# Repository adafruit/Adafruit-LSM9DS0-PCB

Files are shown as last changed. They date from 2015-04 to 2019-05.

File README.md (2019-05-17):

# Adafruit LSM9DS0 PCB (Discontinued)
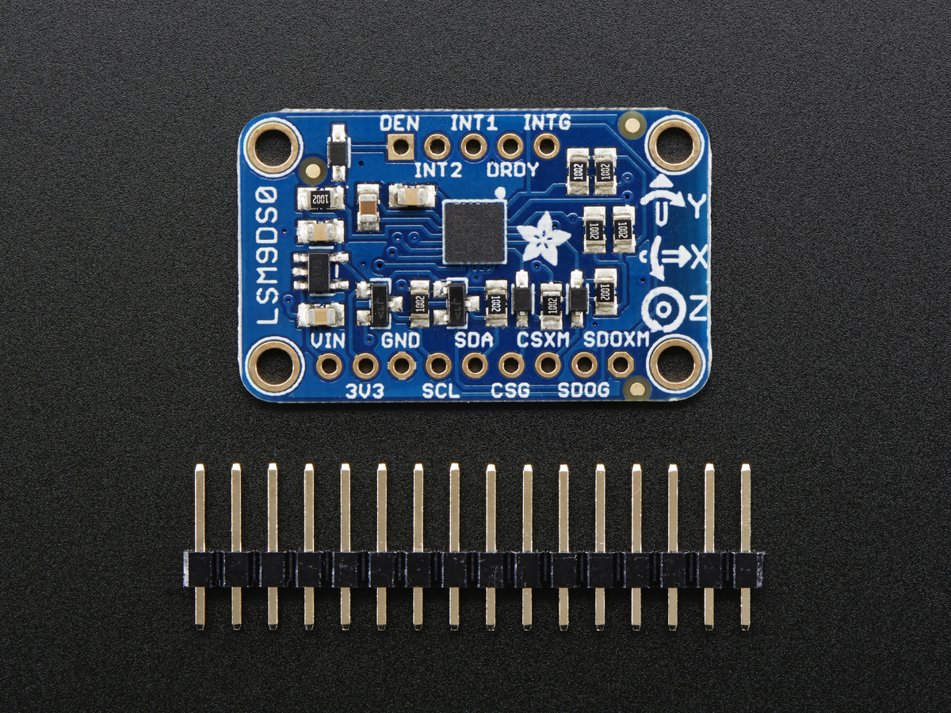
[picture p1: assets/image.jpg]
<a href="http://www.adafruit.com/products/2021"><br/>
Click here to purchase one from the Adafruit shop</a>

When we saw the new LSM9DS0 from ST micro we thought - wow this could really make for a great breakout, at a very nice price! Design your own activity or motion tracker with all the data... We spun up a breakout board that has all the extra circuitry you'll want, like a 3V regulator and level shifting circuitry so it can be used by 3V or 5V power/logic microcontrollers like the Arduino.

PCB files for Adafruit LSM9DS0 9-DOF Sensor PCB. The format is EagleCAD schematic and board layout.
- https://www.adafruit.com/products/2021

### License

Adafruit invests time and resources providing this open source design, please support Adafruit and open-source hardware by purchasing products from [Adafruit](https://www.adafruit.com)!

All text above must be included in any redistribution

Designed by Limor Fried/Ladyada for Adafruit Industries.
Creative Commons Attribution/Share-Alike, all text above must be included in any redistribution. 
See license.txt for additional information.

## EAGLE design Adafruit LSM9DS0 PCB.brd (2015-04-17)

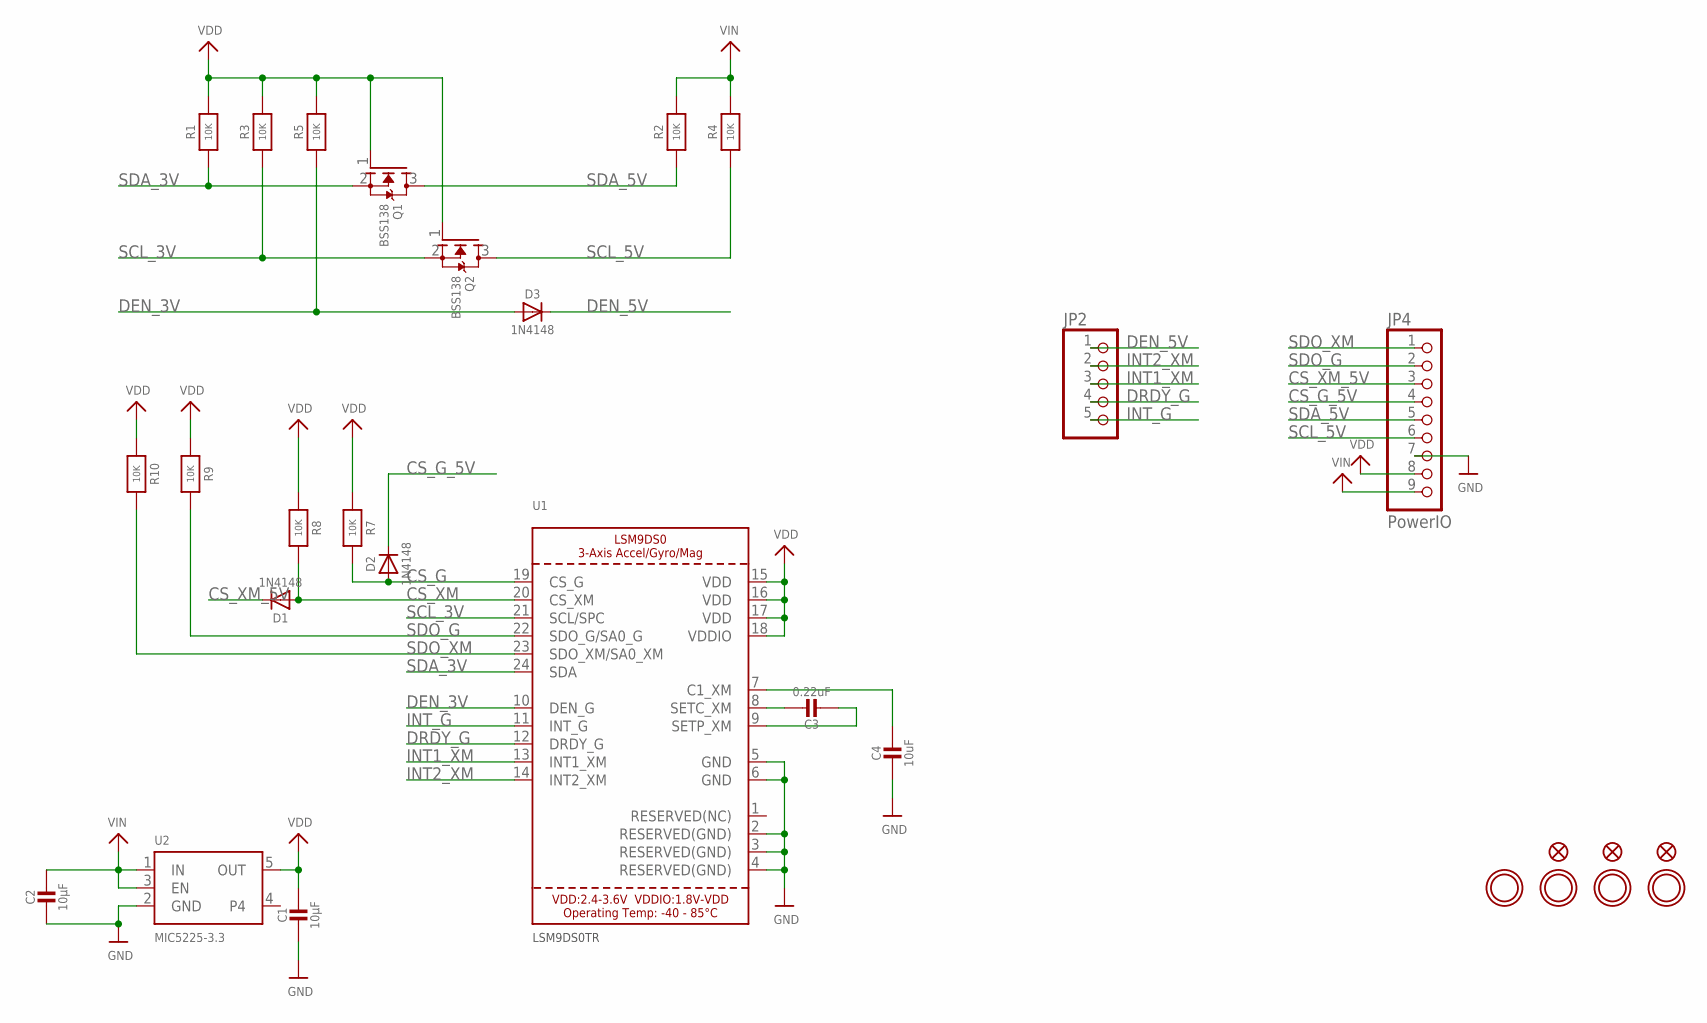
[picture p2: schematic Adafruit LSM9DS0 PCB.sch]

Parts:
C1, C2: 10µF; 0805-NO
C3: 0.22uF; 0805-NO
C4: 10uF; 0805-NO
D1, D2, D3: 1N4148; SOD-323
FID1, FID2, FID3: FIDUCIAL""; FIDUCIAL_1MM
JP2: HEADER-1X570MIL; 1X05_ROUND_70
JP4: PowerIO; 1X09_ROUND_70
Q1, Q2: BSS138; SOT23-WIDE
R1, R2, R3, R5, R7, R8, R9, R10: 10K; 0805-NO
R4: 10K; _0805MP
U1: LSM9DS0TR; LGA24_4X4MM
U2: MIC5225-3.3; SOT23-5
U$4, U$5, U$6, U$7: MOUNTINGHOLE2.5; MOUNTINGHOLE_2.5_PLATED

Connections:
CS_G: D2.A, R7.2, U1.19 (CS_G)
CS_G_5V: D2.C, JP4.4
CS_XM: D1.A, R8.2, U1.20 (CS_XM)
CS_XM_5V: D1.C, JP4.3
DEN_3V: D3.A, R5.1, U1.10 (DEN_G)
DEN_5V: D3.C, JP2.1
DRDY_G: JP2.4, U1.12 (DRDY_G)
GND: C1.2, C2.2, C4.2, JP4.7, U1.2 (RESERVED(GND)), U1.3 (RESERVED(GND)), U1.4 (RESERVED(GND)), U1.5 (GND), U1.6 (GND), U2.2 (GND)
INT1_XM: JP2.3, U1.13 (INT1_XM)
INT2_XM: JP2.2, U1.14 (INT2_XM)
INT_G: JP2.5, U1.11 (INT_G)
unnamed: C3.1, U1.8 (SETC_XM)
unnamed: C3.2, U1.9 (SETP_XM)
unnamed: C4.1, U1.7 (C1_XM)
SCL_3V: Q2.2 (S), R3.1, U1.21 (SCL/SPC)
SCL_5V: JP4.6, Q2.3 (D), R4.1
SDA_3V: Q1.2 (S), R1.1, U1.24 (SDA)
SDA_5V: JP4.5, Q1.3 (D), R2.1
SDO_G: JP4.2, R9.2, U1.22 (SDO_G/SA0_G)
SDO_XM: JP4.1, R10.2, U1.23 (SDO_XM/SA0_XM)
VDD: C1.1, JP4.8, Q1.1 (G), Q2.1 (G), R1.2, R3.2, R5.2, R7.1, R8.1, R9.1, R10.1, U1.15 (VDD), U1.16 (VDD), U1.17 (VDD), U1.18 (VDDIO), U2.5 (OUT)
VIN: C2.1, JP4.9, R2.2, R4.2, U2.1 (IN), U2.3 (EN)

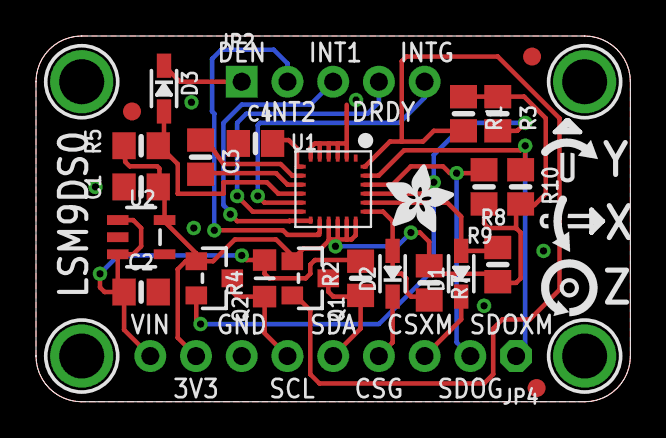
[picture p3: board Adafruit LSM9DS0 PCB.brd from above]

Board: 2 copper layers, 33.0 x 20.3 mm, 31 parts (0 on the bottom side), 22 nets.

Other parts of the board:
U$14: SYMBOL_GYROXYZ_YREV_10MM
U$23: ADAFRUIT_3.5MM

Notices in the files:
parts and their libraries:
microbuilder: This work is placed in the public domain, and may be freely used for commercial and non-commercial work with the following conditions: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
